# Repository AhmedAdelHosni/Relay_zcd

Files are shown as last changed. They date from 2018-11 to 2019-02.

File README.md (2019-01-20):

UPDATE 20.01.2019:
Replaced Replay with Omron G5Q-1-EU DC12

UPDATE 19.12.2018:
- Tested today the relay with Arduino UNO on pin 2 which is configured with PULL UP resistor. The circuit worked very good and the capacitor successfully reported only LOW as long as the AC light is ON, and HIGH as long as the AC is OFF. 

TODO: Test the circuit with long wiring more than 25 meters and put the capacitor near the controller itself and monitor the performance.
The above TODO has been verified successfully 

# Relay_zcd
Relay circuit to control a relay and detect the status of the AC switch using SFH620A optocoupler. 
The idea is to be used in a Smart House to be able to connect the relay with a 3 way switch. It is important to detect the light state so that the application can decide whether to turn off or on the relay. 
The optocoupler is normally pulled to HIGH and goes LOW when the AC is rising which turns on the LED in the optocoupler. When the LED is ON the transistor in the SFH620A will connect the output Signal to GND.
Normally the pin wil be low for ~9ms and high for ~1ms. To avoid this pulsing the idea is to add a capacitor with value 0.1uF to delay the rising of the pin to HIGH when the AC is at zero crossing detection.

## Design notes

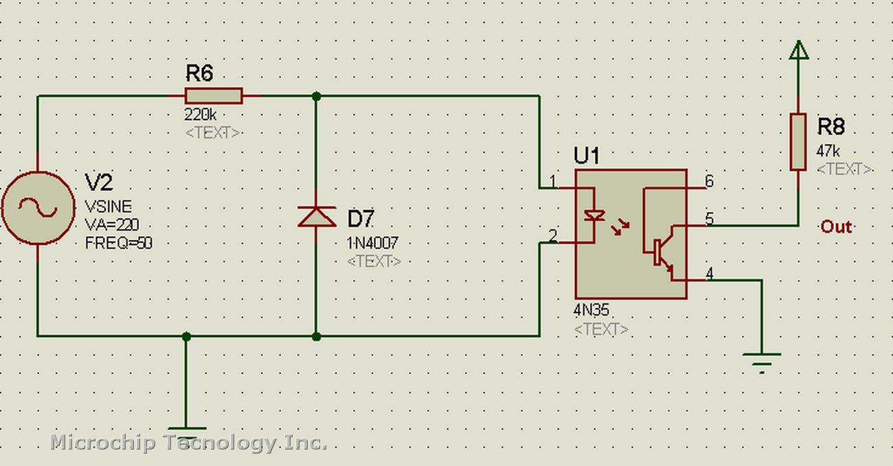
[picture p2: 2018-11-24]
Photos/220v_one_diode__4n25.jpg

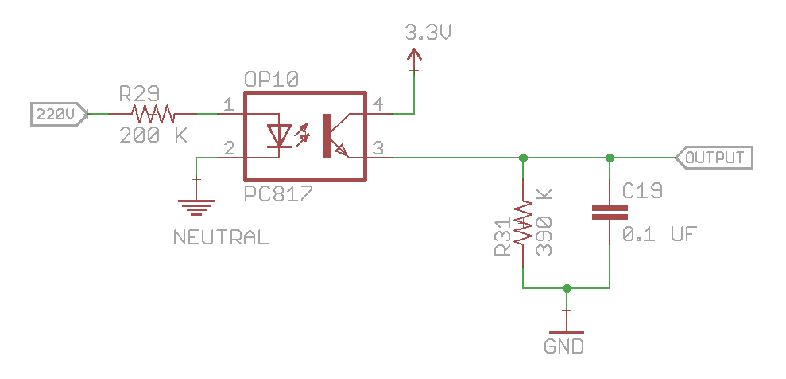
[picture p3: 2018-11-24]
Photos/jApay.png

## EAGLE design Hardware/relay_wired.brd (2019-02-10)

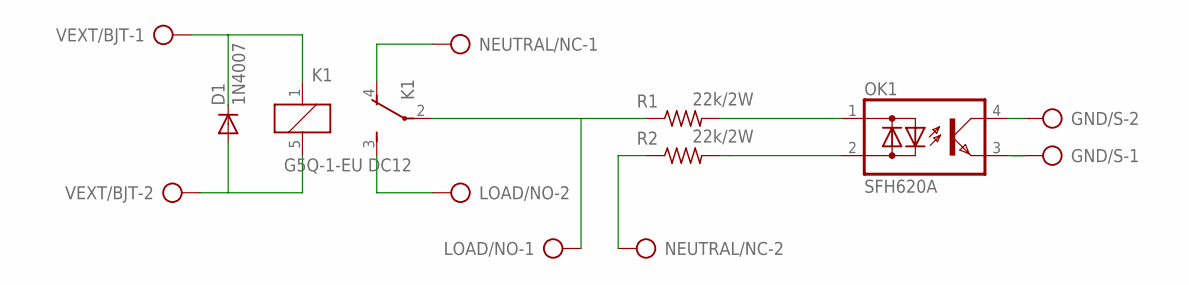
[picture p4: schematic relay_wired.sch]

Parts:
D1: 1N4007; D-5
GND/S: AK500/2
K1: G5Q-1-EU DC12; G5SB
LOAD/NO: AK500/2
NEUTRAL/NC: AK500/2
OK1: SFH620A; DIL04
R1, R2: 22k/2W; 0207/12
VEXT/BJT: AK500/2

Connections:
unnamed: OK1.2 (AC2), R2.2
unnamed: OK1.1 (AC1), R1.2
unnamed: GND/S.2, OK1.4 (C)
unnamed: NEUTRAL/NC.2, R2.1
unnamed: GND/S.1, OK1.3 (E)
unnamed: K1.3 (S), LOAD/NO.2
unnamed: D1.C, K1.1, VEXT/BJT.1
unnamed: D1.A, K1.5 (2), VEXT/BJT.2
unnamed: K1.2, LOAD/NO.1, R1.1
unnamed: K1.4 (O), NEUTRAL/NC.1

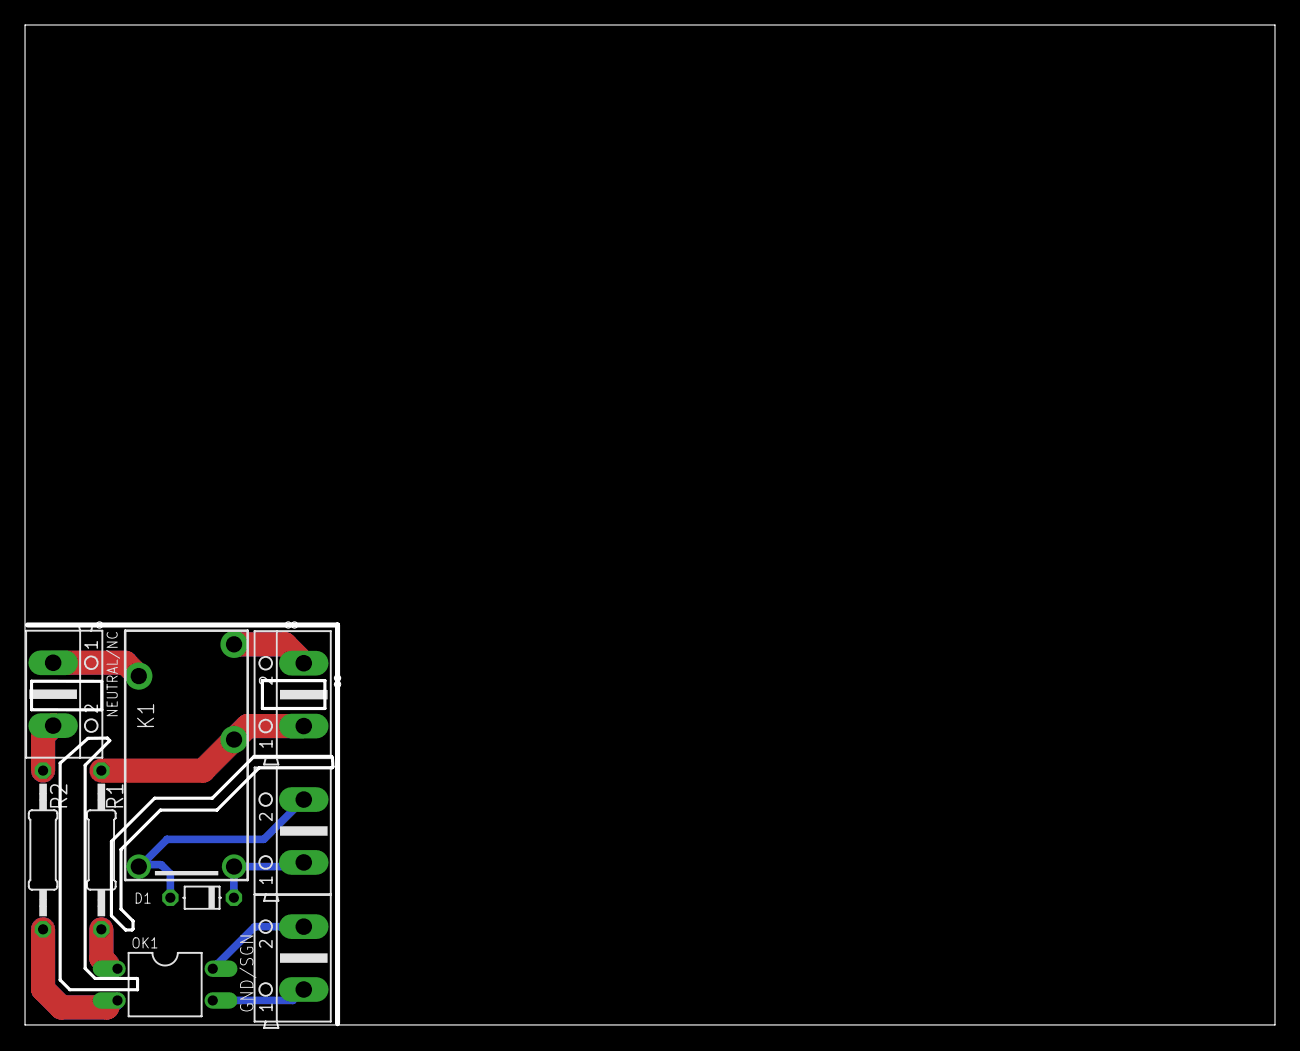
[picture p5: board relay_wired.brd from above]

Board: 2 copper layers, 100.0 x 80.0 mm, 9 parts (0 on the bottom side), 10 nets.

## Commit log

2018-11-24 Create Schematics
    First commit, created schematics for turning ON/OFF a relay + detecting
    the status of the Relay using a bridge rectifier and an opto coupler.
    Circuit not tested yet and passive values are not defined.
    [relay_wired.brd, relay_wired.sch]
2018-11-26 Layout of board 33 x 33
    Layout 33 x 33 board
    [relay_wired.brd, relay_wired.sch]
2018-12-06 Change layout to 25x40mm
    - Change the layout to 25x40 mm since the max board size in the free eagle version is 160mm2 (100x80)
    - Added text on pcb board layout and fixed trace width
    [relay_wired.brd, relay_wired.sch]
2018-12-15 Branch for new design using SFH620A
    Due to design layout size limitation - after fixing parts size - it was not possible to fit in the 25x40 layout a pc817 and a DB107 for detecting zero crossing. Thus this branch is to replace both with the SFH620A IC instead.
    - Changed the terminal block size from 2.54 mm to 5 mm pith instead since this was available in the market.
    - Changed the relay to SONGLE SRD-05VDC-SL-C design. Library is added also
    - Changed resistors value to 0207/12 to fit 22k / 1W resistor value.
    - Changed pic817 and DB107 with SFH620A
    - reroute pcb layout again.
    Todo:
    - Creepage
    - Double layer for high voltage side.
    [relay_wired.brd, relay_wired.sch]
2018-12-19 Invert NC and NO name tags
    Changes in schematic.
    [relay_wired.brd, relay_wired.sch]
2019-01-20 Branching for Omron G5Q-1-EU DC12 relay
    - Replaced relay to Omron G5Q-1-EU DC12
    - Board size reduced from 40x25 to 32x25
    [relay_wired.brd, relay_wired.sch]
2019-01-20 [BUG] Relay was set to mirror by mistake
    - A major bug while reviewing where the relay was set to mirror.
    - Updated gerb274x.cam to generate silk screen for bottom also
    [relay_wired.brd, relay_wired.sch]
2019-01-24 Routing and creepage
    - Routed the circuit
    - Added creepage as lines not polygon
    - Review is done. Shall be a stable version but not tested yet.
    [relay_wired.brd, relay_wired.sch]
2019-02-10 Add some creepage
    [relay_wired.brd]
